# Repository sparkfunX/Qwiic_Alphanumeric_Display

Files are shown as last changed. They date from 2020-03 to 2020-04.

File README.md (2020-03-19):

SparkX Qwiic Alphanumeric Display
========================================

Qwiic Alphanumeric Display - Red (https://cdn.sparkfun.com/assets/parts/1/5/1/8/3/16427-Demo-01.jpg)

[*Qwiic Alphanumeric Display - Red (SPX-16427)*](https://www.sparkfun.com/products/16427)

Qwiic Alphanumeric Display - Blue (https://cdn.sparkfun.com/assets/parts/1/5/1/8/2/16426-Demo-01.jpg)

[*Qwiic Alphanumeric Display - Blue (SPX-16426)*](https://www.sparkfun.com/products/16426)

Qwiic Alphanumeric Display - Purple (https://cdn.sparkfun.com/assets/parts/1/5/1/8/1/16425-Demo-01.jpg)

[*Qwiic Alphanumeric Display - Purple (SPX-16425)*](https://www.sparkfun.com/products/16425)

Qwiic Alphanumeric Display - Pink (https://cdn.sparkfun.com/assets/parts/1/5/1/1/2/16391-Demo-01.jpg)

[*Qwiic Alphanumeric Display - Pink (SPX-16391)*](https://www.sparkfun.com/products/16391)

The SparkFun Qwiic Alphanumeric Display is a 14-segment, 4 digit alphanumeric display with the Hotlek HT16K33 LED Driver. The I2C address is configurable, so daisy-chain up to 4 displays on one bus! Looking for the library? Click [*here*](https://github.com/sparkfun/SparkFun_Alphanumeric_Display_Arduino_Library)

SparkFun labored with love to design this board. Feel like supporting open source hardware? 
Buy a [board]() from SparkFun!

Repository Contents
-------------------

* **/Documents** - Data sheet for the LED Driver and Alphanumeric Displays (Blue and Red)
* **/Hardware** - Eagle design files (.brd, .sch)
* **/Production** - Production panel files (.brd) within the Production folder

License Information
-------------------

This product is _**open source**_! 

Please review the LICENSE.md file for license information. 

If you have any questions or concerns on licensing, please contact technical support on our [SparkFun forums](https://forum.sparkfun.com/viewforum.php?f=152).

Distributed as-is; no warranty is given.

- Your friends at SparkFun.

_<COLLABORATION CREDIT>_

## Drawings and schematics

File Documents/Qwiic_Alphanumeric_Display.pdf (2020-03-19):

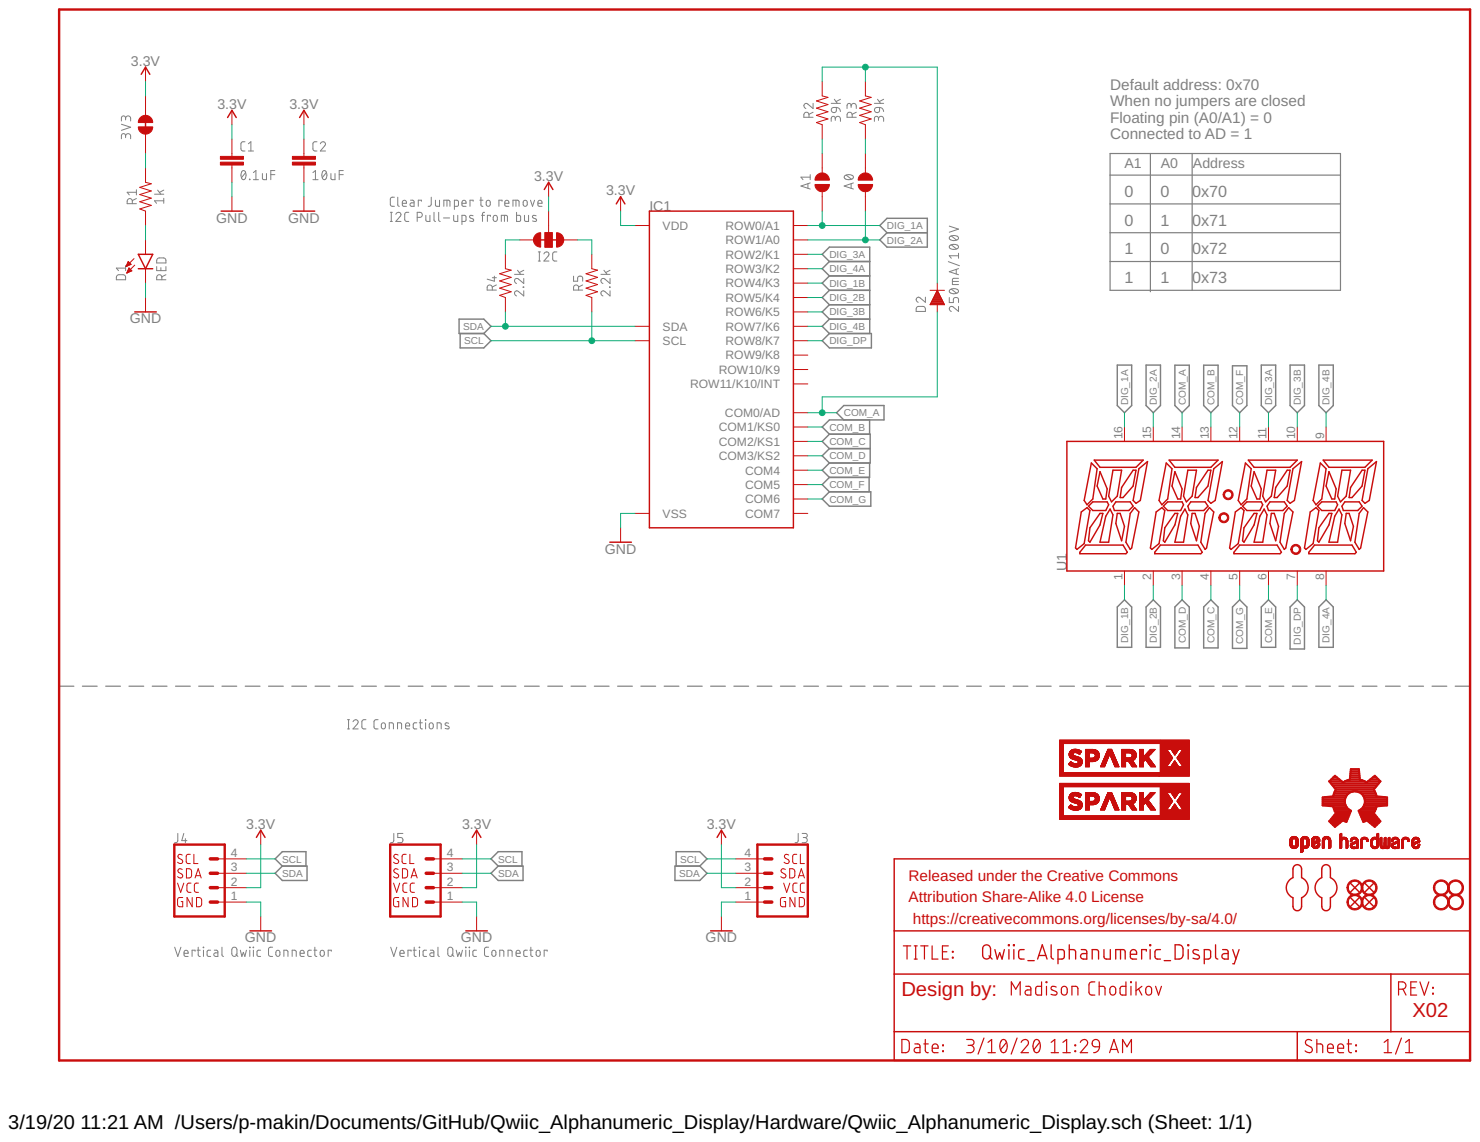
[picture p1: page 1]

Default address: 0x70
When no jumpers are closed
Floating pin (A0/A1) = 0
Connected to AD = 1

A1 | 0 A0 | 0x70 Address 0

Released under the Creative Commons Attribution Share-Alike 4.0 License

https://creativecommons.org/licenses/by-sa/4.0/

3/19/20 11:21 AM /Users/p-makin/Documents/GitHub/Qwiic_Alphanumeric_Display/Hardware/Qwiic_Alphanumeric_Display.sch (Sheet: 1/1)

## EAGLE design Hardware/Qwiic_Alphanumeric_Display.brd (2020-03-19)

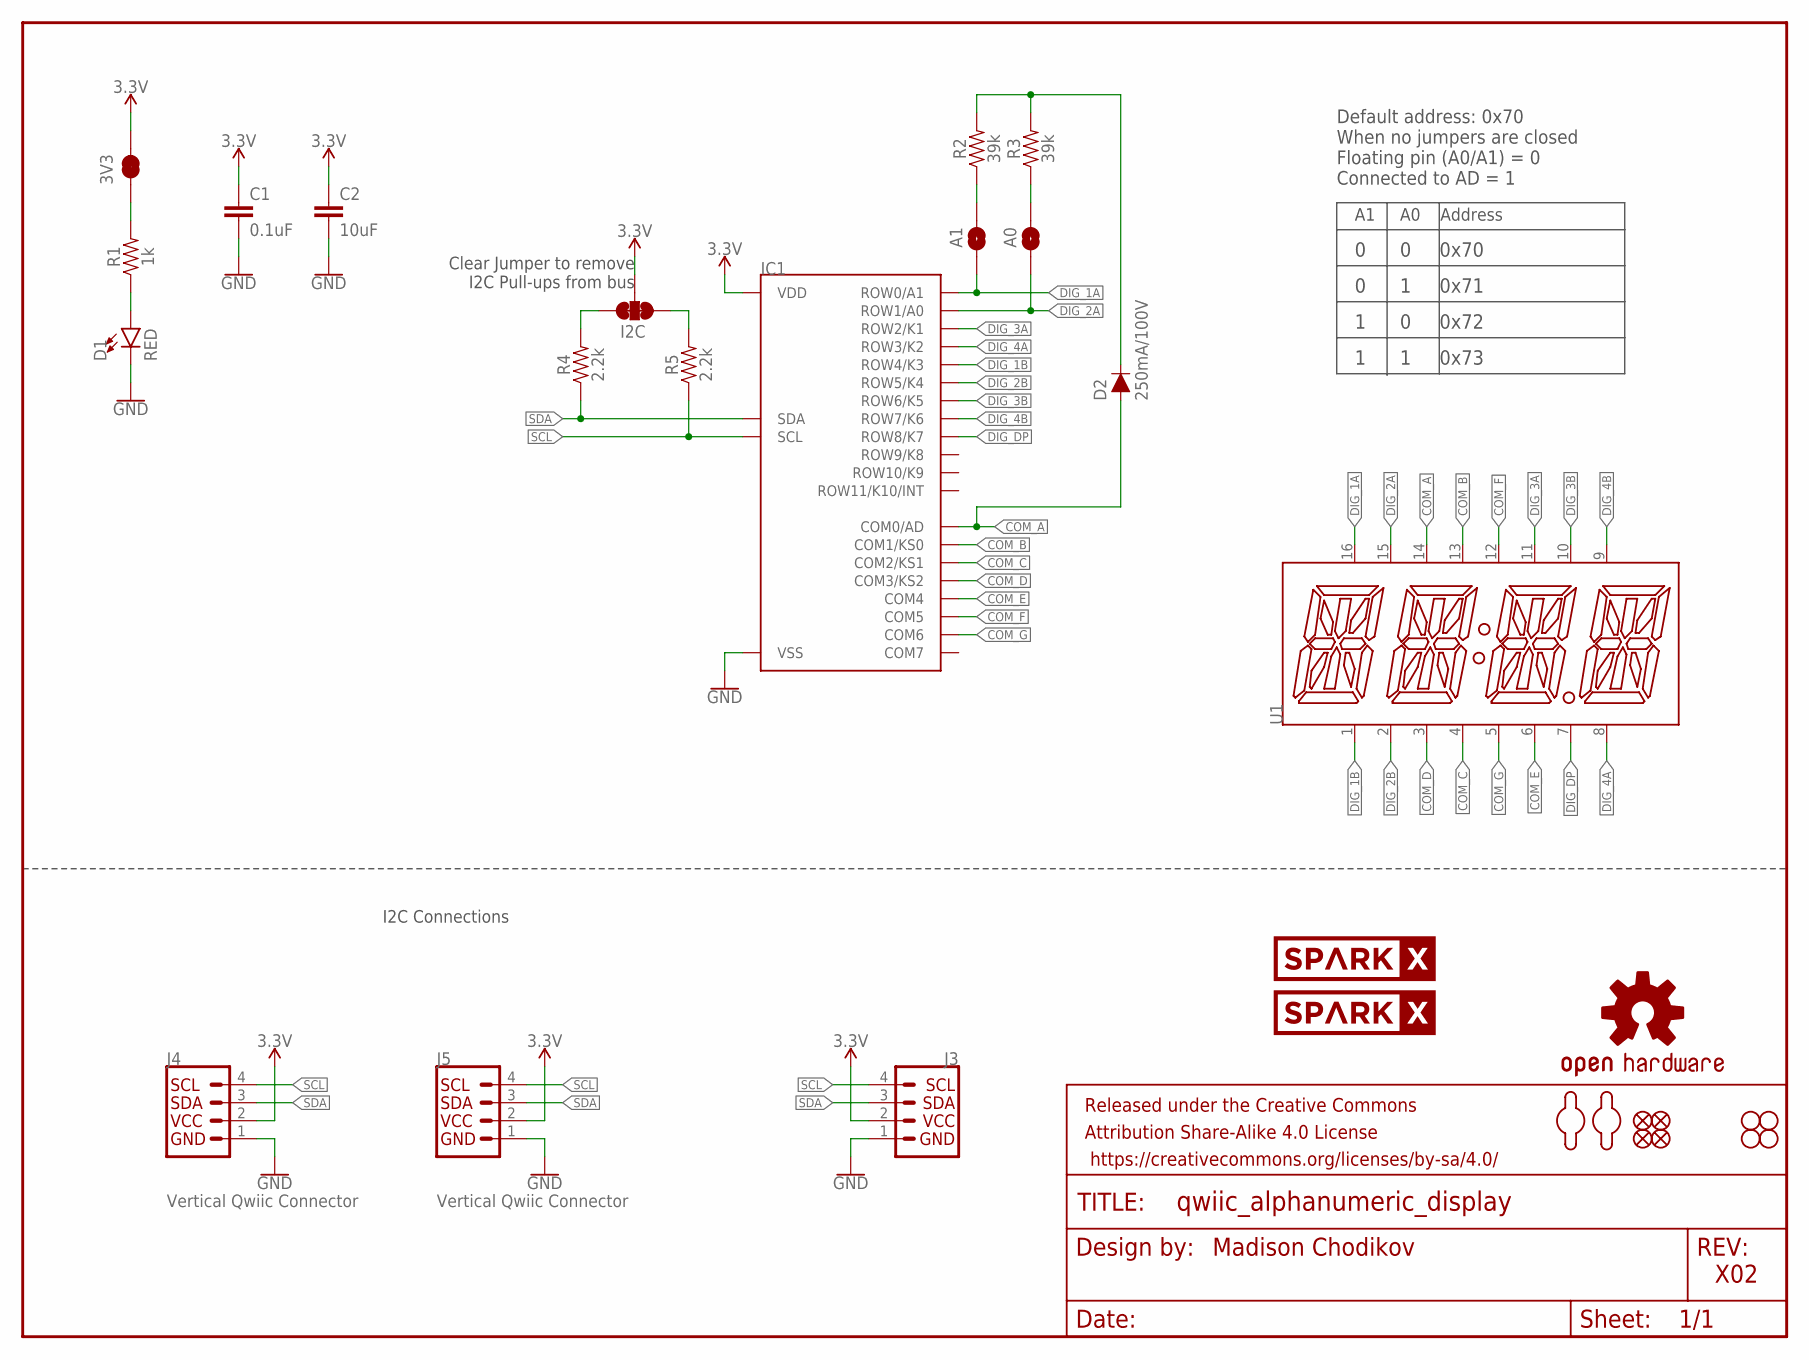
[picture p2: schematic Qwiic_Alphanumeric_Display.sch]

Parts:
3V3: JUMPER-SMT_2_NC_TRACE_SILK; SMT-JUMPER_2_NC_TRACE_SILK
A0, A1: JUMPER-SMT_2_NO_SILK; SMT-JUMPER_2_NO_SILK
C1: 0.1uF; 0603
C2: 10uF; 0603
D1: RED; LED-0603
D2: 250mA/100V; SOD-323
FD1, FD2, FD3, FD4: FIDUCIAL1X2; FIDUCIAL-1X2
FRAME1: FRAME-LETTER; CREATIVE_COMMONS
H1, H2, H3, H4: STAND-OFF
I2C: JUMPER-SMT_3_2-NC_TRACE_SILK; SMT-JUMPER_3_2-NC_TRACE_SILK
IC1: HT16K33
J3: I2C_STANDARD_NO_SILK; 1X04_NO_SILK
J4, J5: Vertical Qwiic Connector; JST04_1MM_VERT
LOGO1: OSHW-LOGOMINI; OSHW-LOGO-MINI
R1: 1k; 0603
R2, R3: 39k; 0603
R4, R5: 2.2k; 0603
U1: SILSMART_DISPLAY
U$7, U$8: SPARKX-LOGO4; SPARKX-MEDIUM
U$18, U$19: MOUNTING_HOLE_M2-0.4X6

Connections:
3.3V: 3V3.2, C1.1, C2.1, I2C.2, IC1.24 (VDD), J3.2, J4.2, J5.2
COM_A: D2.A, IC1.2 (COM0/AD), U1.14 (COM_A)
COM_B: IC1.3 (COM1/KS0), U1.13 (COM_B)
COM_C: IC1.4 (COM2/KS1), U1.4 (COM_C)
COM_D: IC1.5 (COM3/KS2), U1.3 (COM_D)
COM_E: IC1.6 (COM4), U1.6 (COM_E)
COM_F: IC1.7 (COM5), U1.12 (COM_F)
COM_G: IC1.8 (COM6), U1.5 (COM_G1)
DIG_1A: A1.1, IC1.21 (ROW0/A1), U1.16 (DIG_1A)
DIG_1B: IC1.17 (ROW4/K3), U1.1 (DIG_1B)
DIG_2A: A0.1, IC1.20 (ROW1/A0), U1.15 (DIG_2A)
DIG_2B: IC1.16 (ROW5/K4), U1.2 (DIG_2B)
DIG_3A: IC1.19 (ROW2/K1), U1.11 (DIG_3A)
DIG_3B: IC1.15 (ROW6/K5), U1.10 (DIG_3B)
DIG_4A: IC1.18 (ROW3/K2), U1.8 (DIG_4A)
DIG_4B: IC1.14 (ROW7/K6), U1.9 (DIG_4B)
DIG_DP: IC1.13 (ROW8/K7), U1.7 (DIG_DP)
GND: C1.2, C2.2, D1.C, IC1.1 (VSS), J3.1, J4.1, J5.1
unnamed: D1.A, R1.1
unnamed: A1.2, R2.1
unnamed: A0.2, R3.1
unnamed: I2C.1, R5.2
unnamed: I2C.3, R4.2
unnamed: D2.C, R2.2, R3.2
unnamed: 3V3.1, R1.2
SCL: IC1.22 (SCL), J3.4, J4.4, J5.4, R5.1
SDA: IC1.23 (SDA), J3.3, J4.3, J5.3, R4.1

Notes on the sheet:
Madison Chodikov
I2C Connections
Clear Jumper to remove I2C Pull-ups from bus
A1 A0 Address
0 0 0x70
0 1 0x71
1 0 0x72
1 1 0x73
Default address: 0x70 When no jumpers are closed Floating pin (A0/A1) = 0 Connected to AD = 1
X02

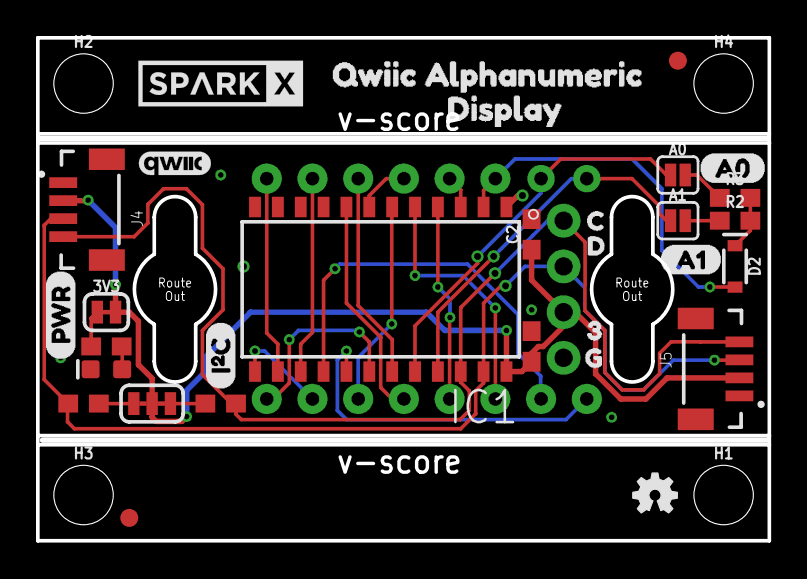
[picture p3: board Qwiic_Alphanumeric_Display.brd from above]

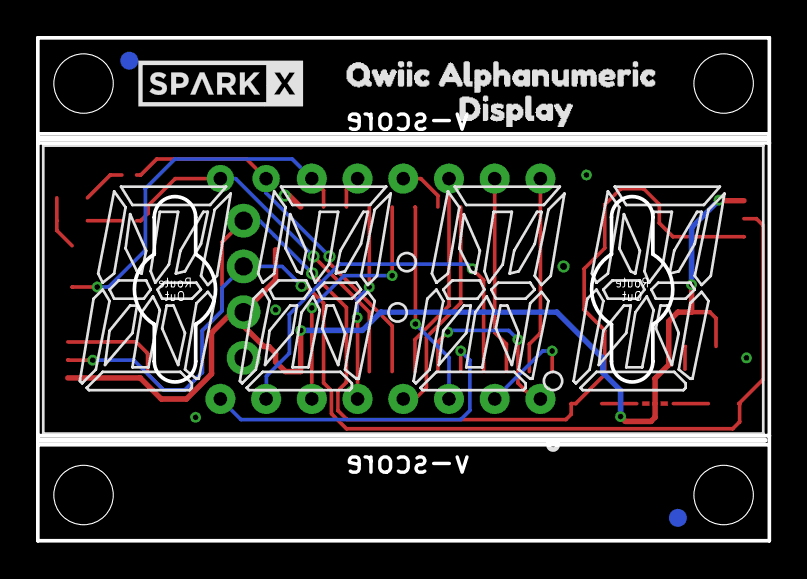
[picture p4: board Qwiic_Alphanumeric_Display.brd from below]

Board: 2 copper layers, 40.6 x 27.9 mm, 45 parts (6 on the bottom side), 27 nets.

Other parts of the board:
U$1: 32
U$2: C0
U$3: PWR5
U$4: D1
U$5: G3
U$6: QWIIC_4MM
U$10: I_SUPER2_C-()-04
U$13, U$15: QWIIC_ALPHANUMERIC0
U$16, U$17: DISPLAY1
U$20: A00
U$21: A11

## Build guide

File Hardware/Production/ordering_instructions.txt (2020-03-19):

panel size, 219x149mm
PCB thickness, 1.6mm
number of layers, 2
soldermask color, Black
silkscreen color, White
oz copper, 1oz
finish, HASL lead free
stencils, top+bottom
pcs per panel, 25
min trace width, 0.2032mm / 0.0080in
min drill size, 0.3048mm / 0.0120in

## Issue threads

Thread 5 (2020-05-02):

missing dimentions

shmulike, 2020-05-02:
Hello.
Where can I find the dimensions of the display, board and mounting holes?

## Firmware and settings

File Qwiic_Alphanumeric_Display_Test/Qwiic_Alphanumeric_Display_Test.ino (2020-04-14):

/********************************************************************
 * This example rapid tests the hardware to verify Qwiic Alphanumeric
 * builds.
 * 
 * Priyanka Makin @ SparkFun Electronics
 * Original Creation Date: March 17, 2020
 *******************************************************************/
#include <Wire.h>
#include <SparkFun_Alphanumeric_Display.h>
HT16K33 display;

const int LED = 13;

void setup()
{
  Serial.begin(115200);
  Serial.println("Qwiic Alphanumeric Display Test");
  Wire.begin();
  pinMode(LED, OUTPUT);
}

void loop()
{
  if (display.begin() == true) {
    digitalWrite(LED, HIGH);
    Serial.println("Alphanumeric detected!");
    display.print("Milk");
  } else {
    digitalWrite(LED, LOW);
    Serial.println("Nothing detected!");
  }
}

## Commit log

2019-07-24 Created Board Layout and Schematic
    [Qwiic_Alphanumeric_Display.brd, Qwiic_Alphanumeric_Display.sch]
2019-07-24 New Board Layout
    The pins were remapped with the LED Driver and the Display to create a better board layout.
    [Qwiic_Alphanumeric_Display.brd, Qwiic_Alphanumeric_Display.sch]
2019-07-25 Created new Board
    Recreated the board in the new Branch with different pin mappings between the HT16K33 and the LED Display for easier routing
    [Qwiic_Alphanumeric_Display.brd, Qwiic_Alphanumeric_Display.sch]
2019-07-25 Added Panelized Board and Gerber Files
    Updated the HT16K33 Footprint, fixed the board files to match the footprint, added the panelized production board and gerber files for ordering the board
    [Qwiic_Alphanumeric_Display-Panel.GBL, Qwiic_Alphanumeric_Display-Panel.GBO, Qwiic_Alphanumeric_Display-Panel.GBS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]
2019-07-26 Moved Decoupling Cap
    Moved the decoupling capacitor next to the LED driver to resolve the GitHub issue
    [Qwiic_Alphanumeric_Display.brd]
2020-02-03 New pin assignments
    Next: route address jumpers, etc
    [Qwiic_Alphanumeric_Display.brd, Qwiic_Alphanumeric_Display.sch]
2020-02-06 Rev X02 of Qwiic Alpha?
    Still needs Nate's look-over. Tighter layout, mounting holes, address/power jumpers. Needs V score lines? Where will the silkscreen go?
    [Qwiic_Alphanumeric_Display.brd, Qwiic_Alphanumeric_Display.sch]
2020-02-07 Rev X02 ordered!
    [Qwiic_Alphanumeric_Display-Panel.GBL, Qwiic_Alphanumeric_Display-Panel.GBO, Qwiic_Alphanumeric_Display-Panel.GBS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]
2020-02-19 Added missing product ID's
    [Qwiic_Alphanumeric_Display.brd, Qwiic_Alphanumeric_Display.sch]
2020-03-09 New decoupling cap
    [Qwiic_Alphanumeric_Display-Panel.GBL, Qwiic_Alphanumeric_Display-Panel.GBO, Qwiic_Alphanumeric_Display-Panel.GBS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]
2020-03-19 Corrected sch/brd files and production outputs
    I seemed to not have the right version of this board when I was wordking from home. Luckily, I had uploaded the files with the double decoupling caps to Sparkle. So I pulled those and fixed this repo...
    [Qwiic_Alphanumeric_Display-Panel.GBL, Qwiic_Alphanumeric_Display-Panel.GBO, Qwiic_Alphanumeric_Display-Panel.GBS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]
2020-03-19 Generated new .pdf of schematic
    With double decoupling caps

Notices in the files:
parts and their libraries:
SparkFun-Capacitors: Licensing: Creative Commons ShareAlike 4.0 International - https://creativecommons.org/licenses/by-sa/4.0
